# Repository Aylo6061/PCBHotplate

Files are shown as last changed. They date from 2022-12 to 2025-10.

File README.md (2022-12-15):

# PCBHotplate
A USB C powered PCB-based hotplate, with separable heater elements.

There are several PCB-project directories, HPcontroller contains the controller, while HPheater contains the heater.

# Inputs and Indicators
D_PD_POW indicates PD power is on
D_3v3_POW indicated 3v3 power is on
D_HOT indicates the plate is hot! dont touch!
D_HB is dicates that data is being sent or received on the serial port
D_MODE indicates the program mode is ON
D_RUN indicates the program or heater is running
D_HEAT indicates the heater is on
D_RTD indicates the RTD protection is tripped

# Bom (rough)

flyback diode - at least 25V Vr, capable of ~5A average current (overkill).  STR8100LBF would work.
capacitor- at least 25-30V probably like 100uF?  depends on switching frequency.
fet driver NCP81071B
Fet AOSD32334C dual nfet
non inverting buffer SN74HCS125PWR

# TODO

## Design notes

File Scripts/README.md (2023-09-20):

# Scripts

heaterPlugin.py is a kicad plugin.  It needs to be copied to your kicad plugin directory. This direcory can be found in pcbnew via tools>external plugins>open plugin directory. Once the plugin is copied, go to tools>external plugins>refresh plugins, and then it should be possible to use tools>external plugins>heater plugin to generate a heater trace.

This trace is continuous (closed), and should be "snipped" on an edge to connect it to whatever is supplying power to the heater.

plot design may be manually edited to give you the desired design plot for a heater trace.  see [this](https://aylo6061.com/2022/12/15/pcb-hot-plate-state-of-the-art/) blog post for more information.

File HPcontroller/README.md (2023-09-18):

# README

some future stuff will go here

# BUGS

pin 1 and 3 are swapped on U3, which makes the thermisor protection circuit not work.  I cut R9 jumper to fix "fix" this, at some point I'll verify that it works by bodge wiring.

GPIO 9 is routed to the MODE switch, however GPIO 9 is also the boot strapping pin to force the bootloader to turn on- therefore it must be switched to PROG when the code is programmed/when the micro boots.

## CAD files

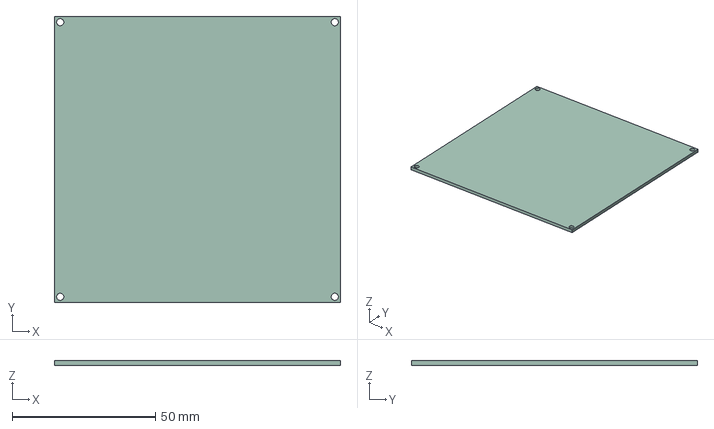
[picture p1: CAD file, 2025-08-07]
HPheater/HPheater/HPheater.step
100.0 x 100.0 x 1.60 mm

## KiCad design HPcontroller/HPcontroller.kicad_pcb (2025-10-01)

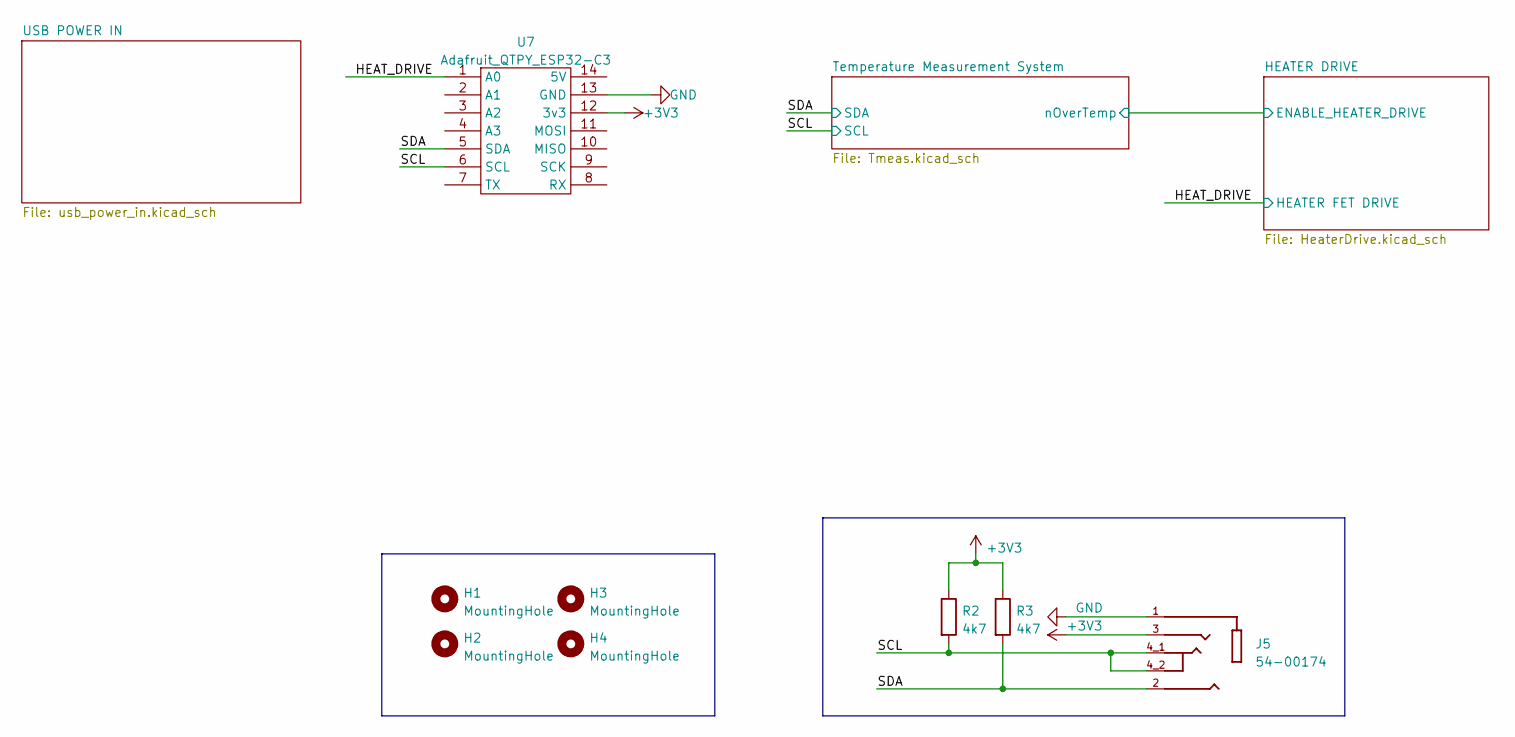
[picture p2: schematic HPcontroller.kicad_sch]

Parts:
H1, H2, H3, H4: MountingHole; MountingHole_2.7mm_M2.5
J5: 54-00174; TENSILITY_54-00174; PARTREV A; Digikey PN 839-54-00174CT-ND
R2, R3: 4k7; R_0805_2012Metric_Pad1.20x1.40mm_HandSolder; MPN RC0805JR-074K7L; Digikey PN 311-4.7KARCT-ND
U7: Adafruit_QTPY_ESP32-C3; XIAO-ESP32C3-SMD-cutout

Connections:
+3V3: J5.3, R2.1, R3.1, U7.12 (3v3); also elsewhere on the board
/HEAT_DRIVE: U7.1 (A0); also elsewhere on the board
/SCL: J5.4_1, J5.4_2, R2.2, U7.6 (SCL); also elsewhere on the board
/SDA: J5.2, R3.2, U7.5 (SDA); also elsewhere on the board
GND: J5.1, U7.13 (GND); also elsewhere on the board

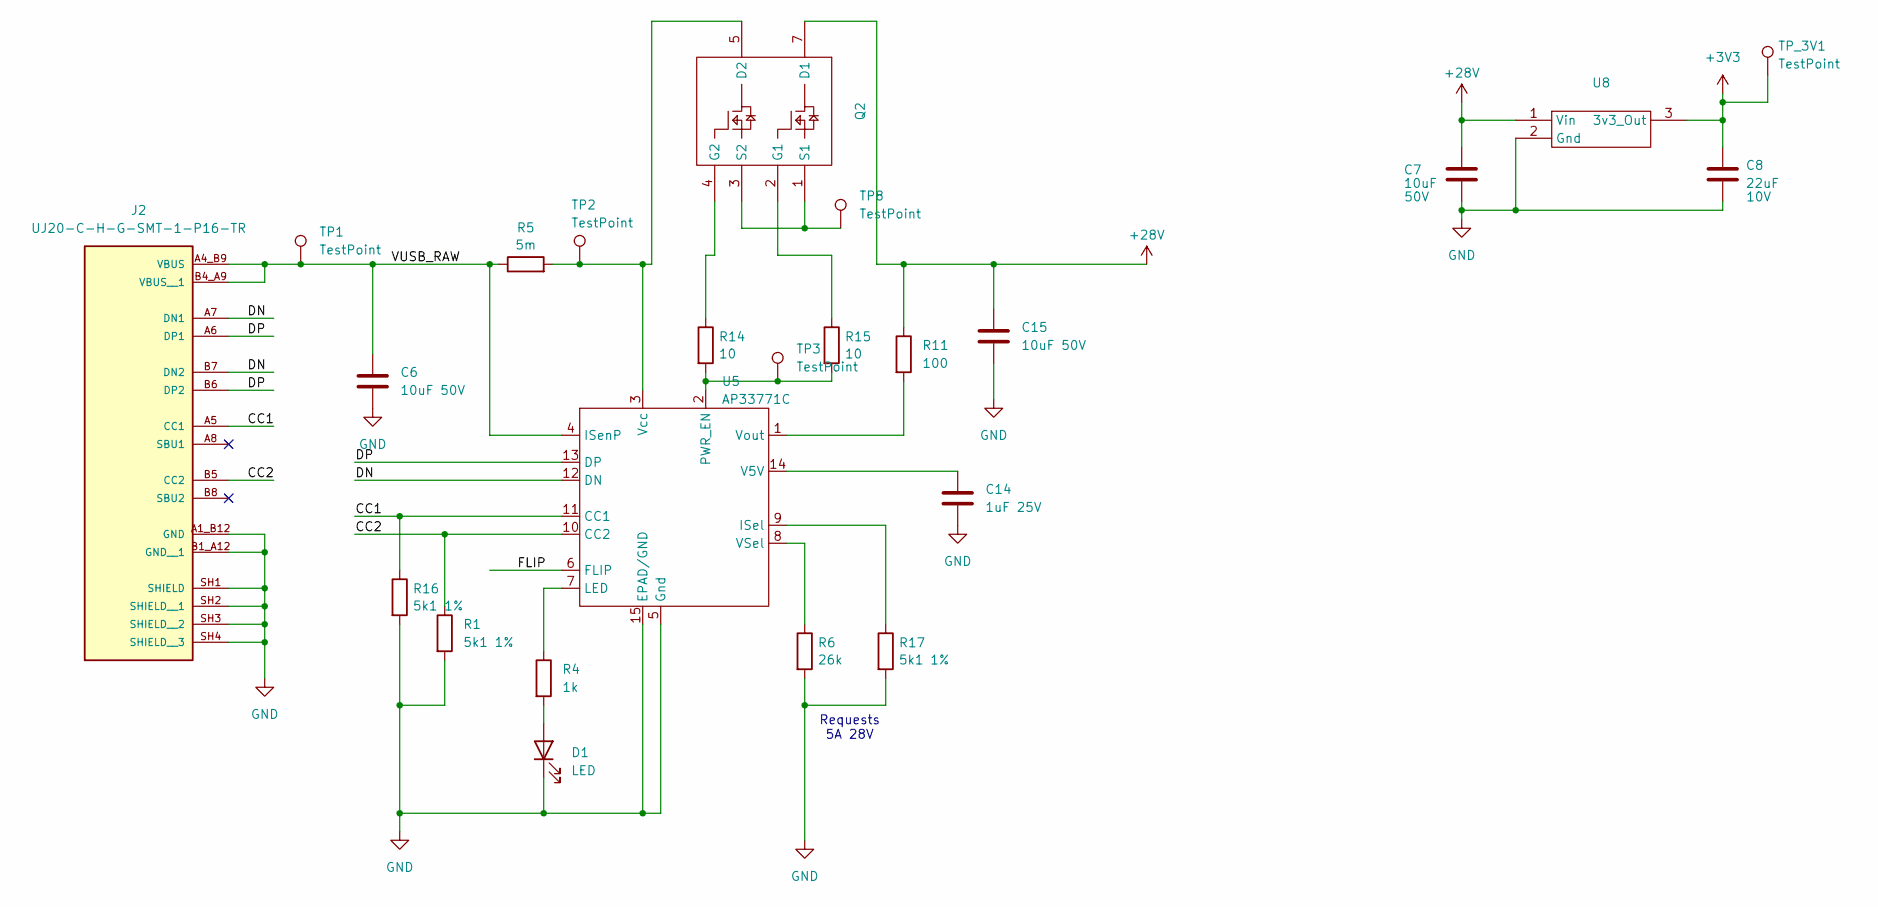
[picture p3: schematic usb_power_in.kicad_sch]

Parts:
C6, C15: 10uF 50V; C_1206_3216Metric_Pad1.33x1.80mm_HandSolder; MPN CL31A106KBHNNNE
C7: 10uF; C_0805_2012Metric; Voltage 50V; MPN GRM21BR61H106KE43L; Digikey PN 490-18663-1-ND
C8: 22uF; C_0603_1608Metric; Voltage 10V; MPN CL10A226MP8NUNE; Digikey PN CL10A226MP8NUNE
C14: 1uF 25V; C_0402_1005Metric; MPN 0402X105K250CT
D1: LED; LED_0603_1608Metric_Pad1.05x0.95mm_HandSolder; MPN B1931USD-20D000814U1930
J2: UJ20-C-H-G-SMT-1-P16-TR; SAMESKY_UJ20-C-H-G-SMT-1-P16-TR; PARTREV 1.0
Q2: LFPAK56D; MPN BUK9K25-40RAX
R1, R16, R17: 5k1 1%; R_0402_1005Metric; MPN RC0402FR-135K1L
R4: 1k; R_0402_1005Metric; MPN RC0402FR-071KL
R5: 5m; R_0603_1608Metric; MPN PA0603FRE470R005L
R6: 26k; R_0603_1608Metric; MPN RC0603FR-0726K1L
R11: 100; R_0402_1005Metric; MPN RC0402FR-07100RL
R14, R15: 10; R_0402_1005Metric; MPN RC0402JR-0710RL
TP1, TP2, TP3, TP8: TestPoint; TestPoint_Pad_D1.5mm
TP_3V1: TestPoint; TestPoint_Pad_D1.5mm
U5: AP33771C; DFN-14-1EP_3x3mm_P0.4mm_EP1.78x2.35mm; MPN AP33771C
U8: D78B33-0.5; MPN D78B33-0.5

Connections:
+3V3: C8.1, TP_3V1.1, U8.3 (3v3_Out); also elsewhere on the board
+28V: C7.1, C15.1, Q2.7 (D1), R11.1, U8.1 (Vin); also elsewhere on the board
/USB POWER IN/CC1: J2.A5 (CC1), R16.1, U5.11 (CC1)
/USB POWER IN/CC2: J2.B5 (CC2), R1.1, U5.10 (CC2)
/USB POWER IN/DN: J2.A7 (DN1), J2.B7 (DN2), U5.12 (DN)
/USB POWER IN/DP: J2.A6 (DP1), J2.B6 (DP2), U5.13 (DP)
/USB POWER IN/FLIP: U5.6 (FLIP)
/USB POWER IN/VUSB_RAW: C6.1, J2.A4_B9 (VBUS), J2.B4_A9 (VBUS__1), R5.1, TP1.1, U5.4 (ISenP)
GND: C6.2, C7.2, C8.2, C14.2, C15.2, D1.1 (K), J2.A1_B12 (GND), J2.B1_A12 (GND__1), J2.SH1 (SHIELD), J2.SH2 (SHIELD__1), J2.SH3 (SHIELD__2), J2.SH4 (SHIELD__3), R1.2, R6.2, R16.2, R17.2, U5.5 (Gnd), U5.15 (EPAD/GND), U8.2 (Gnd); also elsewhere on the board
unnamed: D1.2 (A), R4.2
unnamed: Q2.5 (D2), R5.2, TP2.1, U5.3 (Vcc)
unnamed: Q2.2 (G1), R15.1
unnamed: Q2.4 (G2), R14.1
unnamed: Q2.1 (S1), Q2.3 (S2), TP8.1
unnamed: R17.1, U5.9 (ISel)
unnamed: R4.1, U5.7 (LED)
unnamed: R14.2, R15.2, TP3.1, U5.2 (PWR_EN)
unnamed: C14.1, U5.14 (V5V)
unnamed: R6.1, U5.8 (VSel)
unnamed: R11.2, U5.1 (Vout)

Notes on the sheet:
Requests 5A 28V

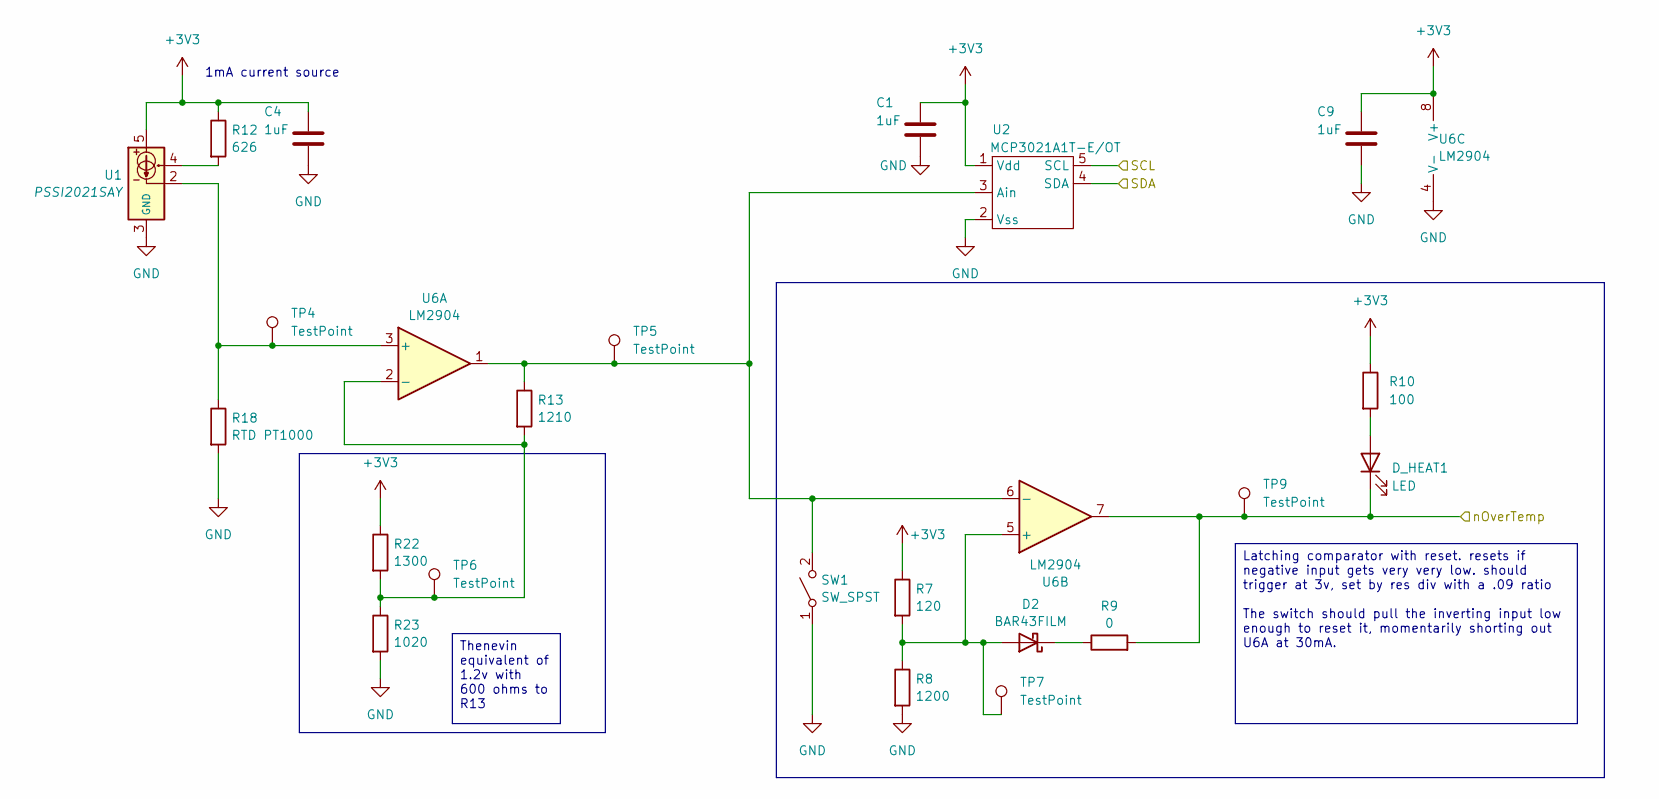
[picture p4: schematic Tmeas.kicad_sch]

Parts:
C1, C4, C9: 1uF; C_0805_2012Metric; MPN CL21B105KAFNNNE; Digikey PN 1276-1066-1-ND
D2: BAR43FILM; SOT-23; MPN BAR43FILM
D_HEAT1: LED; LED_0603_1608Metric_Pad1.05x0.95mm_HandSolder
R7: 120; R_0603_1608Metric; MPN ERJ-3EKF1200V
R8: 1200; R_0603_1608Metric; MPN CR0603-FX-1203ELF
R9: 0; R_0603_1608Metric
R10: 100; R_0603_1608Metric; MPN CRGCQ0805J100R; Digikey PN A130128CT-ND
R12: 626; R_0603_1608Metric; MPN RT0603BRD07626RL
R13: 1210; R_0603_1608Metric; MPN RC0603FR-071K21L
R18: RTD PT1000; R_0805_2012Metric; MPN 30200145
R22: 1300; R_0603_1608Metric; MPN RC0603FR-071K3L
R23: 1020; R_0603_1608Metric; MPN ERJ-3EKF1021V
SW1: SW_SPST; SW_EVQ-P7J01P; MPN EVQ-P7J01P
TP4, TP5, TP6, TP7, TP9: TestPoint; TestPoint_Pad_D1.5mm
U1: PSSI2021SAY; SOT-353_SC-70-5; MPN PSSI2021SAY
U2: MCP3021A1T-E/OT; SOT-23-5; MPN MCP3021A1T-E/OT; Digikey PN MCP3021A1T-E/OTCT-ND
U6: LM2904; MINISO8_3P1X3P2X0P65_STM; MPN LM2904ST

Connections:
+3V3: C1.1, C4.1, C9.1, R7.1, R10.1, R12.1, R22.1, U1.5, U2.1 (Vdd), U6.8 (V+); also elsewhere on the board
/HEATER DRIVE/ENABLE_HEATER_DRIVE: D_HEAT1.1 (K), R9.2, TP9.1, U6.7; also elsewhere on the board
/SCL: U2.5 (SCL); also elsewhere on the board
/SDA: U2.4 (SDA); also elsewhere on the board
GND: C1.2, C4.2, C9.2, R8.2, R18.2, R23.2, SW1.1 (A), U1.3 (GND), U2.2 (Vss), U6.4 (V-); also elsewhere on the board
unnamed: D2.1 (A), R7.2, R8.1, TP7.1, U6.5 (+)
unnamed: D2.3 (K), R9.1
unnamed: D_HEAT1.2 (A), R10.2
unnamed: R12.2, U1.4
unnamed: R13.1, SW1.2 (B), TP5.1, U2.3 (Ain), U6.1, U6.6 (-)
unnamed: R18.1, TP4.1, U1.2, U6.3 (+)
unnamed: R13.2, R22.2, R23.1, TP6.1, U6.2 (-)

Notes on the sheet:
1mA current source
Thenevin equivalent of 1.2v with 600 ohms to R13
Latching comparator with reset. resets if negative input gets very very low. should trigger at 3v, set by res div with a .09 ratio The switch should pull the inverting input low enough to reset it, momentarily shorting out U6A at 30mA.

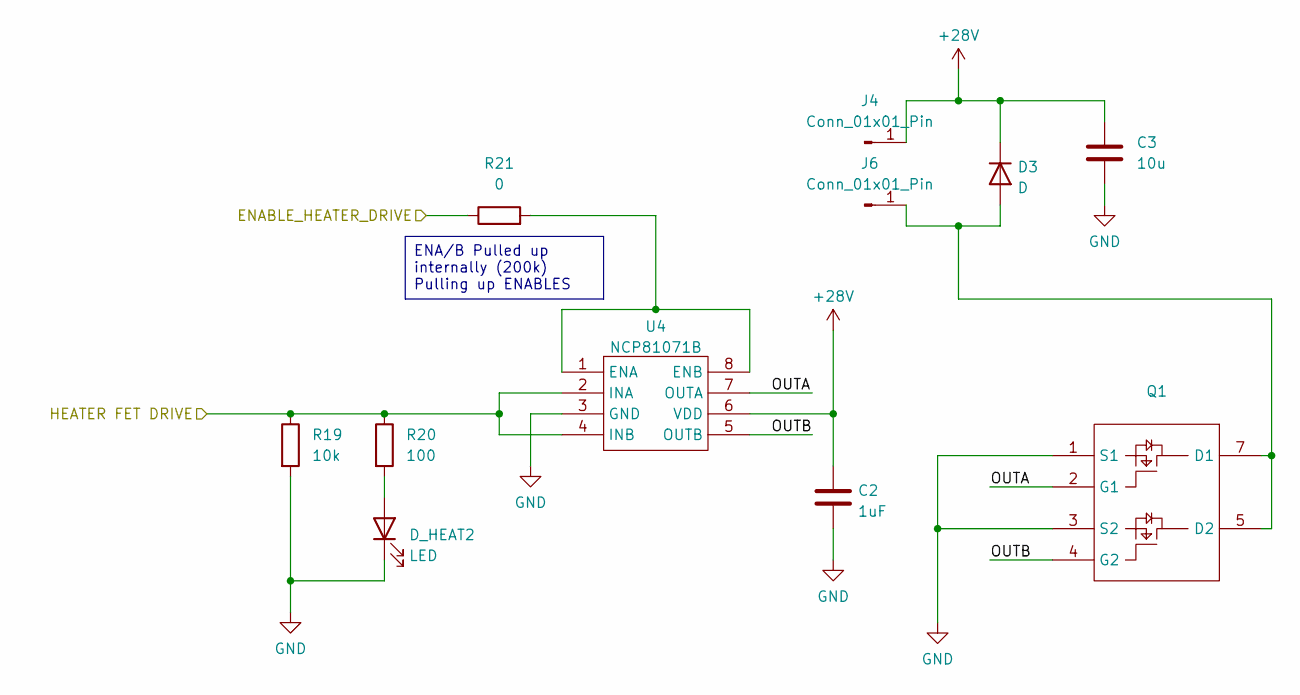
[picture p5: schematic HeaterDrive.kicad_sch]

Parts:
C2: 1uF; C_0805_2012Metric; MPN CL21B105KAFNNNE; Digikey PN 1276-1066-1-ND
C3: 10u; C_0805_2012Metric; Voltage 50V; MPN GRM21BR61H106KE43L; Digikey PN 490-18663-1-ND
D3: D; D_SMB_Handsoldering; MPN STR8100LBF_R1_00701; Digikey PN 3757-STR8100LBF_R1_00701CT-ND
D_HEAT2: LED; LED_0603_1608Metric_Pad1.05x0.95mm_HandSolder
J4, J6: Conn_01x01_Pin; S7051-42R
Q1: LFPAK56D; MPN BUK9K25-40RAX
R19: 10k; R_0805_2012Metric_Pad1.20x1.40mm_HandSolder; MPN RNCP0805FTD10K0; Digikey PN RNCP0805FTD10K0CT-ND
R20: 100; R_0805_2012Metric_Pad1.20x1.40mm_HandSolder; MPN CRGCQ0805J100R; Digikey PN A130128CT-ND
R21: 0; SolderJumper-2_P1.3mm_Bridged_RoundedPad1.0x1.5mm
U4: NCP81071B; SOIC-8_3.9x4.9mm_P1.27mm; MPN NCP81071BDR2G; Digikey PN NCP81071BDR2GOSCT-ND

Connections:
+28V: C2.1, C3.1, D3.1 (K), J4.1, U4.6 (VDD); also elsewhere on the board
/HEATER DRIVE/ENABLE_HEATER_DRIVE: R21.1; also elsewhere on the board
/HEATER DRIVE/OUTA: Q1.2 (G1), U4.7 (OUTA)
/HEATER DRIVE/OUTB: Q1.4 (G2), U4.5 (OUTB)
/HEAT_DRIVE: R19.1, R20.1, U4.2 (INA), U4.4 (INB); also elsewhere on the board
GND: C2.2, C3.2, D_HEAT2.1 (K), Q1.1 (S1), Q1.3 (S2), R19.2, U4.3 (GND); also elsewhere on the board
unnamed: D3.2 (A), J6.1, Q1.5 (D2), Q1.7 (D1)
unnamed: D_HEAT2.2 (A), R20.2
unnamed: R21.2, U4.1 (ENA), U4.8 (ENB)

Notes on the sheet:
ENA/B Pulled up internally (200k) Pulling up ENABLES

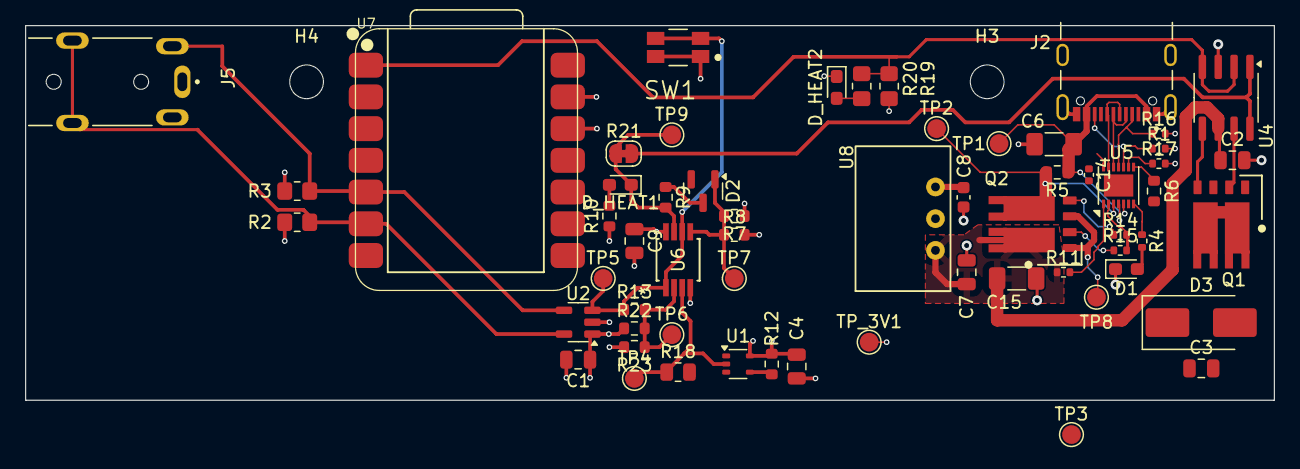
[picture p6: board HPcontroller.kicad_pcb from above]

Board: 4 copper layers, 100.0 x 30.0 mm, 64 parts (0 on the bottom side), 35 nets.

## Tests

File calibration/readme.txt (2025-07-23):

to use:

navigate here and use: `jupyter notebook`
go to http://localhost:8888

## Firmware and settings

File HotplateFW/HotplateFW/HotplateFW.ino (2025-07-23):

#include <Adafruit_GFX.h>
#include <Adafruit_SSD1306.h>
#include <Adafruit_MCP23X17.h>
#include <Wire.h>
#include <MCP3X21.h>


#define SCREEN_WD 128
#define SCREEN_HT 32

#define OLED_RESET -1

Adafruit_SSD1306 display(SCREEN_WD, SCREEN_HT, &Wire, OLED_RESET);
Adafruit_MCP23X17 mcp;


#define SDA_PIN D4
#define SLC_PIN D5

#define SEL_A_PIN A3
#define SEL_B_PIN A2
#define INT_PIN D9
#define HEATER_PIN A0

#define DIV_MODE_1k 0
#define DIV_MODE_10k 1
#define DIV_MODE_100k 2

#define BUTTON_PIN_MODE 0   // MCP23XXX pin used for interrupt
#define BUTTON_PIN_DEC 1   // MCP23XXX pin used for interrupt
#define BUTTON_PIN_INC 2   // MCP23XXX pin used for interrupt
#define BUTTON_PIN_RUN 3   // MCP23XXX pin used for interrupt



#define ADC_CUTOFF_VAL_1k 254 //below this adc value, use 10k res div

#define L_1k       852.09
#define X_zero_1k  144.86
#define K_1k         0.0287
#define OFF_1k     -19.57

#define L_10k      1173.59
#define X_zero_10k 69.93
#define K_10k       0.0290
#define OFF_10k   -176.13

MCP3021 mcp3021(0x49);

float targTemp=0;       //target temperature
enum state {heatOff, heatOn};
state currentState = heatOff;


void setupHeater()
{
  if(!ledcSetup(0, 25000, 8))// ch0: 25khz, 8 bit
  {
    Serial.println("Heater pin channel setup failed!");
  }
  else{
    ledcWrite(0, 0); // set initial ch0 output to 0
    ledcAttachPin(HEATER_PIN, 0);
    Serial.println("Heater setup");
  }
}

void heaterPower(int power)
{
  ledcWrite(0, power);
  Serial.print("Heater set to: ");
  Serial.println(power);
}

void bangBang(float currentTemp, float hyst)
{
  if(currentState == heatOff)
  {
    heaterPower(0);
    return;
  }
  if(currentState == heatOn)
  {
  if((targTemp- hyst)> currentTemp){
    heaterPower(240);
  }
  else{
    heaterPower(0);
  }
  }
  return;
}

void set_divider(int mode){
  if(mode == DIV_MODE_1k)
  {
    digitalWrite(SEL_A_PIN,1);
    digitalWrite(SEL_B_PIN,1);
  }
  if(mode == DIV_MODE_10k)
  {
    digitalWrite(SEL_A_PIN,0);
    digitalWrite(SEL_B_PIN,1);
  }
  if(mode == DIV_MODE_100k)
  {
    digitalWrite(SEL_A_PIN,1);
    digitalWrite(SEL_B_PIN,0);
  }
}

void setup() {
  Serial.begin(115200);
  Serial.println("Hotplate Booted:");

  pinMode(SEL_A_PIN, OUTPUT);
  pinMode(SEL_B_PIN, OUTPUT);
  set_divider(DIV_MODE_1k);
  Serial.println("set div mode 1k");
  

  // SSD1306_SWITCHCAPVCC = generate display voltage from 3.3V internally
  if(!display.begin(SSD1306_SWITCHCAPVCC, 0x3C)) { // Address 0x3C for 128x32
    Serial.println(F("SSD1306 allocation failed"));
    for(;;); // Don't proceed, loop forever
  }
  Serial.println("screen begin");

  display.clearDisplay();
  display.setTextSize(3);             
  display.setTextColor(SSD1306_WHITE);
  display.setRotation(2);
  display.setCursor(0,0);
  display.print(" PDHP!");
  display.display();
  display.setTextSize(1);           
  delay(1000);

    if (!mcp.begin_I2C()) {
    Serial.println("Error.");
    while (1);
  }
  Serial.println("mcp exp init...done");

  mcp3021.init();
  Serial.println("mcp adc init...done");
  
//  pinMode(INT_PIN, INPUT_PULLUP);
  mcp.setupInterrupts(true, false, LOW);//mirror interrupts

  // configure button pin for input with pull up
  mcp.pinMode(BUTTON_PIN_MODE, INPUT_PULLUP);
  mcp.pinMode(BUTTON_PIN_DEC, INPUT_PULLUP);
  mcp.pinMode(BUTTON_PIN_INC, INPUT_PULLUP);
  mcp.pinMode(BUTTON_PIN_RUN, INPUT_PULLUP);

  // enable interrupt on button_pin
  mcp.setupInterruptPin(BUTTON_PIN_MODE, LOW);
  mcp.setupInterruptPin(BUTTON_PIN_DEC, LOW);
  mcp.setupInterruptPin(BUTTON_PIN_INC, LOW);
  mcp.setupInterruptPin(BUTTON_PIN_RUN, LOW);
//  attachInterrupt(INT_PIN, mcp_int, FALLING);
  setupHeater();
}

void displayTask(float temp){
  display.clearDisplay();
  display.setCursor(0,0);
  display.print("Targ ");
  display.printf("%3.0f\n",targTemp);
  display.print("Curr ");
  display.printf("%3.0f\n",temp);
  display.print("mode ");
  if(currentState == heatOff)
  {
    display.printf("OFF");  
  }
  if(currentState == heatOn)
  {
    display.printf("HEAT");  
  }
  display.display();
}

unsigned long timeWas;

void checkInputs(){
  unsigned long timeNow=millis();
  if(timeNow-timeWas >=200)
  {
    timeWas = timeNow;
  int button = mcp.getLastInterruptPin();
  mcp.clearInterrupts();
  Serial.print("button ");
  Serial.println(button);
  switch(button)
  {
    case 255:
      break;
    case 0: //toggle mode
      if (currentState == heatOff){
        currentState = heatOn;
        Serial.println("heatOn");
        break;
      }
      if (currentState == heatOn){
        currentState = heatOff;
        Serial.println("heatOff");
        break;
      }
      break;
      
    case 1: //dec temp
      if(targTemp>=5){
        targTemp-=5;
      }
      break;
    case 2: //inc temp
      if(targTemp<200){
        targTemp+=5;
      }
      break;
    case 3: //nothing!
      break;
  }
  }
}

float runConversion( int adcval, float L, float xnought, float k, float off)
{
  float ret;
  ret = (xnought*k-log((-1*(L+off-adcval))/(off-adcval)))/k;
  return ret;
}

float getTemp(){
  float ret;
  int result;
  //read 1k
  set_divider(DIV_MODE_1k);
  result = mcp3021.read();
  if(result>ADC_CUTOFF_VAL_1k)
  {
    ret = runConversion(result, L_1k,  X_zero_1k, K_1k, OFF_1k);
    return ret;
  }
  set_divider(DIV_MODE_10k);
  result = mcp3021.read();
  ret = runConversion(result, L_10k,  X_zero_10k, K_10k, OFF_10k);
  return ret;
}

void loop(void) {
  
  float tempNow;
  tempNow = getTemp();
  heaterPower(0);
  timeWas = millis();
  Serial.println("entering main loop...");
    
  while(1){
    checkInputs();
    tempNow = getTemp();
    displayTask(tempNow);
    bangBang(tempNow, 5);
  }
}

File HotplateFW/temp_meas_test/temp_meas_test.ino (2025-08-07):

#include <OneWire.h>
#include <DallasTemperature.h>
#include <AceButton.h>
#include <Adafruit_GFX.h>
#include <Adafruit_SSD1306.h>
#include <Wire.h>
#include <MCP3X21.h>


#define SCREEN_WD 128
#define SCREEN_HT 32

#define OLED_RESET -1

Adafruit_SSD1306 display(SCREEN_WD, SCREEN_HT, &Wire, OLED_RESET);

using namespace ace_button;

#define SDA_PIN D4
#define SLC_PIN D5

#define SEL_A_PIN A3
#define SEL_B_PIN A2

#define DIV_MODE_1k 0
#define DIV_MODE_10k 1
#define DIV_MODE_100k 2

#define OW_BUS_PIN D3
#define HEATER_PIN D0
#define LED_RUN D10
#define LED_HOT A1

#define INC_PIN  D7
#define DEC_PIN  D8
#define STOP_GO  D6
#define PROG_MAN D9

ButtonConfig buttonConfig_STOP_GO;
ButtonConfig buttonConfig_INC;
ButtonConfig buttonConfig_DEC;

AceButton button_STOP_GO(& buttonConfig_STOP_GO);
AceButton button_DEC(& buttonConfig_INC);
AceButton button_INC(& buttonConfig_DEC);

void handleEvent_STOP_GO(AceButton*, uint8_t, uint8_t);
void handleEvent_DEC(AceButton*, uint8_t, uint8_t);
void handleEvent_INC(AceButton*, uint8_t, uint8_t);

OneWire  TcBus(OW_BUS_PIN);  // on pin 0, AKA A3
DallasTemperature Tc(&TcBus);
DeviceAddress TcAddress;

const uint8_t address = 0x49;
const uint16_t ref_voltage = 3300;  // in mV

MCP3021 mcp3021(address);

// function to print a device address
void printAddress(DeviceAddress deviceAddress)
{
  for (uint8_t i = 0; i < 8; i++)
  {
    if (deviceAddress[i] < 16) Serial.print("0");
    Serial.print(deviceAddress[i], HEX);
  }
}

bool tempSensorStart()//startup code for temp sensor
{
  if(TcBus.search(TcAddress))
  {
    Serial.print("Address found: ");
    printAddress(TcAddress);
    Tc.setResolution(TcAddress, 9);
  return 1;
  }
  else{
    return 0;
  }
}

float getTemp()//get the temperature, return it in float degrees c.
{
  Tc.requestTemperatures();
  float tempC = Tc.getTempC(TcAddress);
  return tempC;
}

void terminalErrorBlink()
{
  pinMode(D1, OUTPUT);
  while(1){
      digitalWrite(D1, HIGH);   // turn the LED on 
      delay(200);               // wait for a second
      digitalWrite(D1, LOW);    // turn the LED off
      delay(500);               // wait for a second
      Serial.println("error");
  }
}

void happyBlink()
{
  pinMode(D10, OUTPUT);
  while(1){
      digitalWrite(D10, HIGH);   // turn the LED on 
      delay(200);               // wait for a second
      digitalWrite(D10, LOW);    // turn the LED off
      delay(200);               // wait for a second
      Serial.println(getTemp());
  }
  
}

void setupHeater()
{
  if(!ledcSetup(0, 25000, 8))// ch0: 25khz, 8 bit
  {
    Serial.println("Heater pin channel setup failed!");
    terminalErrorBlink();
  }
  else{
    ledcWrite(0, 0); // set initial ch0 output to 0
    ledcAttachPin(HEATER_PIN, 0);
    Serial.println("Heater setup");
  }
}

void heaterPower(int power)
{
  ledcWrite(0, power);
  Serial.print("Heater set to: ");
  Serial.println(power);
}

void bangBang(float target, float currentTemp, float hyst)
{
  if((target- hyst)> currentTemp){
    heaterPower(200);
  }
  else{
    heaterPower(0);
  }
}

void set_divider(int mode){
  if(mode == DIV_MODE_1k)
  {
    digitalWrite(SEL_A_PIN,1);
    digitalWrite(SEL_B_PIN,1);
  }
  if(mode == DIV_MODE_10k)
  {
    digitalWrite(SEL_A_PIN,0);
    digitalWrite(SEL_B_PIN,1);
  }
  if(mode == DIV_MODE_100k)
  {
    digitalWrite(SEL_A_PIN,1);
    digitalWrite(SEL_B_PIN,0);
  }
}

void setup() {
  delay(1000);
  Serial.begin(115200);
  Serial.println("Hotplate Booted:");

  pinMode(SEL_A_PIN, OUTPUT);
  pinMode(SEL_B_PIN, OUTPUT);
  set_divider(DIV_MODE_1k);
  

  // SSD1306_SWITCHCAPVCC = generate display voltage from 3.3V internally
  if(!display.begin(SSD1306_SWITCHCAPVCC, 0x3C)) { // Address 0x3C for 128x32
    Serial.println(F("SSD1306 allocation failed"));
    for(;;); // Don't proceed, loop forever
  }

  display.clearDisplay();
  display.setTextSize(3);             
  display.setTextColor(SSD1306_WHITE);
  display.setRotation(2);
  display.setCursor(0,0);
  display.print(" PDHP!");
  display.display();
  delay(1000);

  mcp3021.init();

  button_STOP_GO.init(STOP_GO);
  pinMode(STOP_GO, INPUT_PULLUP);
  buttonConfig_STOP_GO.setEventHandler(handleEvent_STOP_GO);
  buttonConfig_STOP_GO.setFeature(ButtonConfig::kFeatureClick);

  button_DEC.init(DEC_PIN);
  pinMode(DEC_PIN, INPUT_PULLUP);
  buttonConfig_DEC.setEventHandler(handleEvent_DEC);
  buttonConfig_DEC.setFeature(ButtonConfig::kFeatureClick);

  button_INC.init(INC_PIN);
  pinMode(INC_PIN, INPUT_PULLUP);
  buttonConfig_INC.setEventHandler(handleEvent_INC);
  buttonConfig_INC.setFeature(ButtonConfig::kFeatureClick);

  pinMode(LED_RUN, OUTPUT);
  pinMode(LED_HOT, OUTPUT);
  setupHeater();
}

float targTemp=0;       //target temperature
bool heatEnabled=0; //heatEnabled = 1 heat up
bool progMode;    //progMode = 1 program mode



  
void loop(void) {
  uint16_t result;

  while(1){
    set_divider(DIV_MODE_1k);
    Serial.print("Div mode 1k, ");
    result = mcp3021.read();
    Serial.print(F("ADC: "));
    Serial.print(result);
    Serial.print(F(", mV: "));
    Serial.println(mcp3021.toVoltage(result, ref_voltage));
    delay(1000);
    set_divider(DIV_MODE_10k);
    Serial.print("Div mode 10k, ");
    result = mcp3021.read();
    Serial.print(F("ADC: "));
    Serial.print(result);
    Serial.print(F(", mV: "));
    Serial.println(mcp3021.toVoltage(result, ref_voltage));
    delay(1000);
    set_divider(DIV_MODE_100k);
    Serial.print("Div mode 100k, ");
    result = mcp3021.read();
    Serial.print(F("ADC: "));
    Serial.print(result);
    Serial.print(F(", mV: "));
    Serial.println(mcp3021.toVoltage(result, ref_voltage));
    delay(1000);

  }
  
  float tempNow;
  tempNow = getTemp();
  heaterPower(0);
    
  while(1){
    tempNow = getTemp();
    
    button_STOP_GO.check();
    button_INC.check();
    button_DEC.check();
    if(heatEnabled)
    {
    digitalWrite(LED_RUN, 1);
    bangBang(targTemp, tempNow, .5);
    Serial.print("Temp is: ");
    Serial.print(tempNow);
    Serial.print(" Target temp is: ");
    Serial.print(targTemp);
    }
    else
    {
      digitalWrite(LED_RUN,0);
      bangBang(0, tempNow, .5);
      Serial.print("Temp is: ");
      Serial.print(tempNow);
      Serial.print(" Target temp is: ");
      Serial.print(targTemp);
    }
    if(tempNow>50)
    {
      digitalWrite(LED_HOT, 1);
    }
    else
    {
      digitalWrite(LED_HOT,0);
    }
  display.clearDisplay();
  display.setTextSize(2);             
  display.setTextColor(SSD1306_WHITE);
  display.setCursor(0,0);
  display.print("Targ ");
  display.printf("%3.0f\n",targTemp);
  display.print("Curr ");
  display.printf("%3.0f",tempNow);
  display.display();
  }
}

void handleEvent_STOP_GO(AceButton* button, uint8_t eventType, uint8_t buttonState)
{
  switch(eventType){
    case AceButton::kEventPressed:
      Serial.println("stopgo");
      heatEnabled = !heatEnabled;
      break;
  }
}
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

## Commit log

2022-11-30 more design is done
    [ThermalProtector.kicad_sch]
2022-11-30 saved more changes
    [HPcontroller.kicad_sch]
2022-12-01 assigned footprints, added some stuff to readme
    [HPcontroller.kicad_sch, ThermalProtector.kicad_sch]
2022-12-02 started layout
    [HPcontroller.kicad_pcb, HPcontroller.kicad_sch, ThermalProtector.kicad_sch]
2022-12-02 routing more. waitingfor PD trigger to arrive
    [HPcontroller.kicad_pcb, HPcontroller.kicad_sch, ThermalProtector.kicad_sch]
2022-12-15 minor pcb change to give TC wires more room
    [HPcontroller.kicad_pcb, HPcontroller.kicad_sch, ThermalProtector.kicad_sch]
2022-12-15 started work on heater
    [HPheater.kicad_pcb, HPheater.kicad_sch]
2022-12-15 added scripts to design and draw heater
2022-12-15 started heater layout. need to make heater smaller to accomodate some kind of mounting holes, need to add mounting for controller
    [HPcontroller.kicad_pcb, HPheater.kicad_pcb, HPheater.kicad_sch]
2022-12-15 fixed minor issues, added mounting
    [HPcontroller.kicad_pcb, HPcontroller.kicad_sch, ThermalProtector.kicad_sch]
2022-12-15 changed heater size, added mounting, refined slot
    [HPheater.kicad_pcb, HPheater.kicad_sch]
2022-12-15 final tweaks/drc to HPheater. DO NOT repour zones, as there is a purposeful short
    [HPheater.kicad_pcb]
2022-12-15 added upllup to thermal protection circuit
    [HPcontroller.kicad_pcb, HPcontroller.kicad_sch, ThermalProtector.kicad_sch]
2023-09-18 started revision
    [HPcontroller.kicad_pcb, HPcontroller.kicad_sch, HPheater.kicad_pcb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]
2023-09-19 design "finished" need to do bom and footprints and layout
    [Controlpad.kicad_sch, HPcontroller.kicad_sch, HeaterDrive.kicad_sch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]
2023-09-19 started routing, finished footprintns
    [Controlpad.kicad_sch, HPcontroller.kicad_pcb, HPcontroller.kicad_sch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]
2023-09-19 finished routing, moving on to heater
    [Controlpad.kicad_sch, HPcontroller.kicad_pcb, HPcontroller.kicad_sch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]
2023-09-20 finished routing heater
    [HPheater.kicad_pcb, HPheater.kicad_sch]
2023-09-20 worked on bom, orderables from dk are in
    [Controlpad.kicad_sch, HPcontroller.kicad_pcb, HPcontroller.kicad_sch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]
2023-10-17 fixed C and R silk swap
    [HPcontroller.kicad_pcb]
2023-10-25 calibration fw
2023-10-25 calibration notebook (jupyter)
2025-08-07 v3 routing
    [Controlpad.kicad_sch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]
2025-09-25 new temp circuit
    [HPcontroller.kicad_pcb, HPcontroller.kicad_sch, HeaterDrive.kicad_sch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]
2025-10-01 finished temp meas stuff, laying out
    [HPcontroller.kicad_pcb, HeaterDrive.kicad_sch, Tmeas.kicad_sch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]
2026-05-12 fixed open on heater
2026-05-12 new gerbers
2026-08-26 Port HotplateFW to PlatformIO, update for new sensor board revision
    - Replace the switched 1k/10k/100k resistor-divider temp circuit with
    the new PT1000 RTD front end (1mA excitation, op-amp linearized to
    [1.078V,1.941V] -> [0.3V,3.0V], read by the MCP3021), converting to
    temperature via the IEC 60751 Callendar-Van Dusen inversion.
    - Fix MODE button toggling multiple times per press: the MCP23X17
    interrupt condition is level-based and keeps re-firing every poll
    while held, so gate the toggle on the pin actually reading released.
    - Replace watchdog-reboot-looping infinite hangs on missing I2C
    devices (OLED/MCP23X17) with retry loops plus an I2C bus scan for
    diagnosability.
    - Tri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
2026-09-14 Add HeaterApp: standalone PCB heater footprint generator
    PySide6 desktop app (HeaterApp/) that draws a heater area with rectangular
    keepouts and arbitrary end pads, fills it with a single serpentine trace
    (corridor + domino matching + 2x2 splice merging, ~100% coverage), sizes the
    trace width for a target resistance, and exports a KiCad footprint with pads,
    copper lines, keepout rule areas and courtyard.
    Includes R-vs-T plot, a thermal analysis tab (CV / PWM / CC drive, flat or
    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
2026-10-13 Switch heater drive to plain GPIO, add 100 ms minimum off time
    The new heater drive is a constant-current MP4423 buck enabled via
    EN/SYNC, so 25 kHz PWM on that pin is unnecessary and likely harmful.
    Drive HEAT_DRIVE as a regular on/off GPIO instead (heaterPower(int) ->
    setHeater(bool)).
    Bang-bang now requires the heater to have been off for at least 100 ms
    before turning back on. On time is not limited.
2026-10-13 Ignore KiCad lock files and local history, untrack generated files
    Add *.lck and .history/ to .gitignore, and stop tracking .kicad_prl,
    fp-info-cache and -backups files that were already covered by ignore
    rules but had been committed earlier.
2026-10-13 Ignore and untrack Gerber and zip fabrication outputs
    Add *.gbr and *.zip to .gitignore and remove the previously tracked
    Gerber files and gerber zips from the index (files kept on disk).
2026-10-13 Ignore and untrack drill and Gerber job files
    Add *.drl and *.gbrjob to .gitignore and remove the previously tracked
    ones from the index (files kept on disk).
